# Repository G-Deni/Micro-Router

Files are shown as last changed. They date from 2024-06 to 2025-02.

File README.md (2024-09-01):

# Micro-Router
This project sets out to solve a simple but niche problem, when using any form of hot-spot in a large area coverage can suffer. Using a mesh-network of Micro-Routers coverage area can be extended for a short time without running any cables. This is achieved by a custom OpenWRT configuration and a onboard battery that should yield ~16hrs of run time.

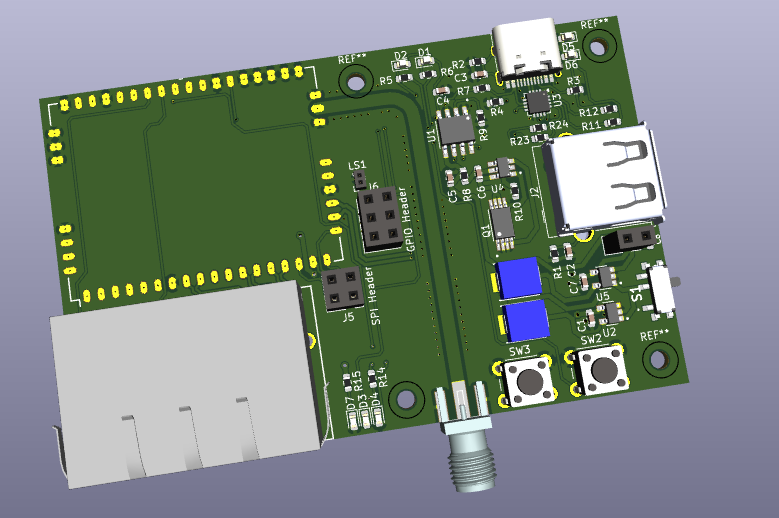
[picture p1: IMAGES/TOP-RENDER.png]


## Features 

### SOM
Each Micro-Router uses a [Carambola2](https://www.8devices.com/products/carambola-2) SOM running [OpenWRT](https://openwrt.org/). 

### Ports
<ul>
  <li>USB-A - Media share capacity</li>
  <li>USB-C - Charging and UART</li>
  <li>2x RJ45 - LAN and WAN</li>
</ul>

### Charge Controller
Powered A 3.3v TP4056 charging circuit with a separate 5v boost converter to power the USB-A port. The charge controller was selected for this project to be cheap, this means while the battery is protected there is no communication between the SOM and the charge controller. There is no safe start of shut down if the battery dies the charge controller will disconnect the battery from the loads. It power switch toggles the boost converters on and off, disconnecting the battery from all loads at the boost converter. The 5v and the 3.3v boost converters are both 500mah and toggled on and off by the same slide switch.

### USB Serial
It has serial output over USB-C to help prevent bricking during development. All of the reset and clock pins are connected to make it as robust as possible, however if there is a problem with the serial connection both the Carambola2 and the serial to USB IC have reset push-buttons. 

### GPIO/SPI Headers
Exposed on the board are two 2.25mm pitch headers one is for SPI screen output (four pin) and one for general GPIO (6 pin).  

### External Antenna
A board mounted SMA connector is impedance matched for 2.4ghz WiFi is exposed for a external antenna to be connected to. There is no internal antenna as the performance is usually very poor.

### Speaker
Two pins are exposed for the speaker one is ground the other is a GPIO. One of the GPIO pins has to be reserved to be used as a speaker. If the extra GPIO pin is needed do not populate the speaker.

## Docking Case
The PCB layout may look rather unconventional but it is intentional. The routers are optimized to be used in a dock configuration.

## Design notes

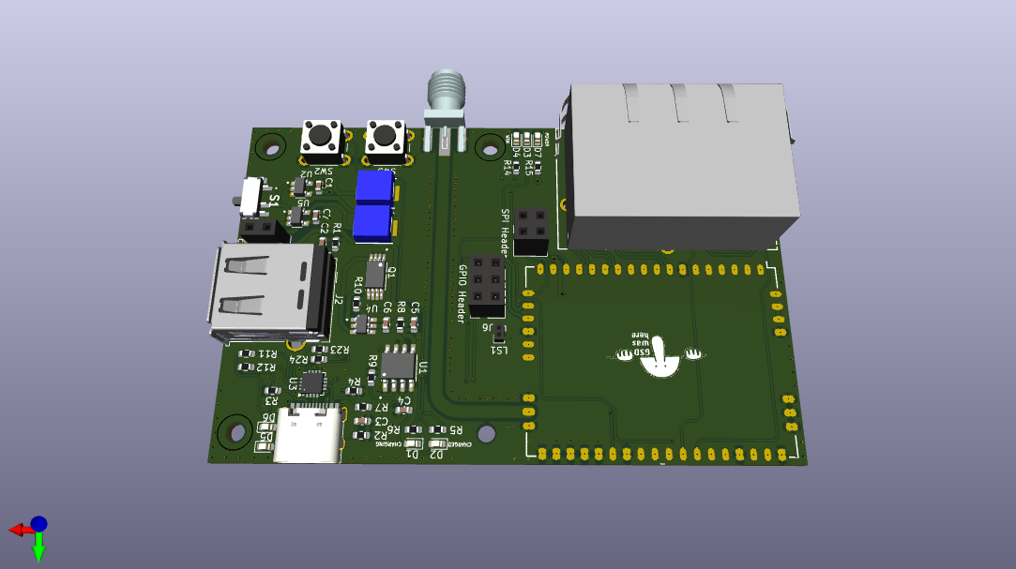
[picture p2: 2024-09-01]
MICRO-ROUTER-PCB/MICRO-ROUTER/MICRO-ROUTER RENDER.png

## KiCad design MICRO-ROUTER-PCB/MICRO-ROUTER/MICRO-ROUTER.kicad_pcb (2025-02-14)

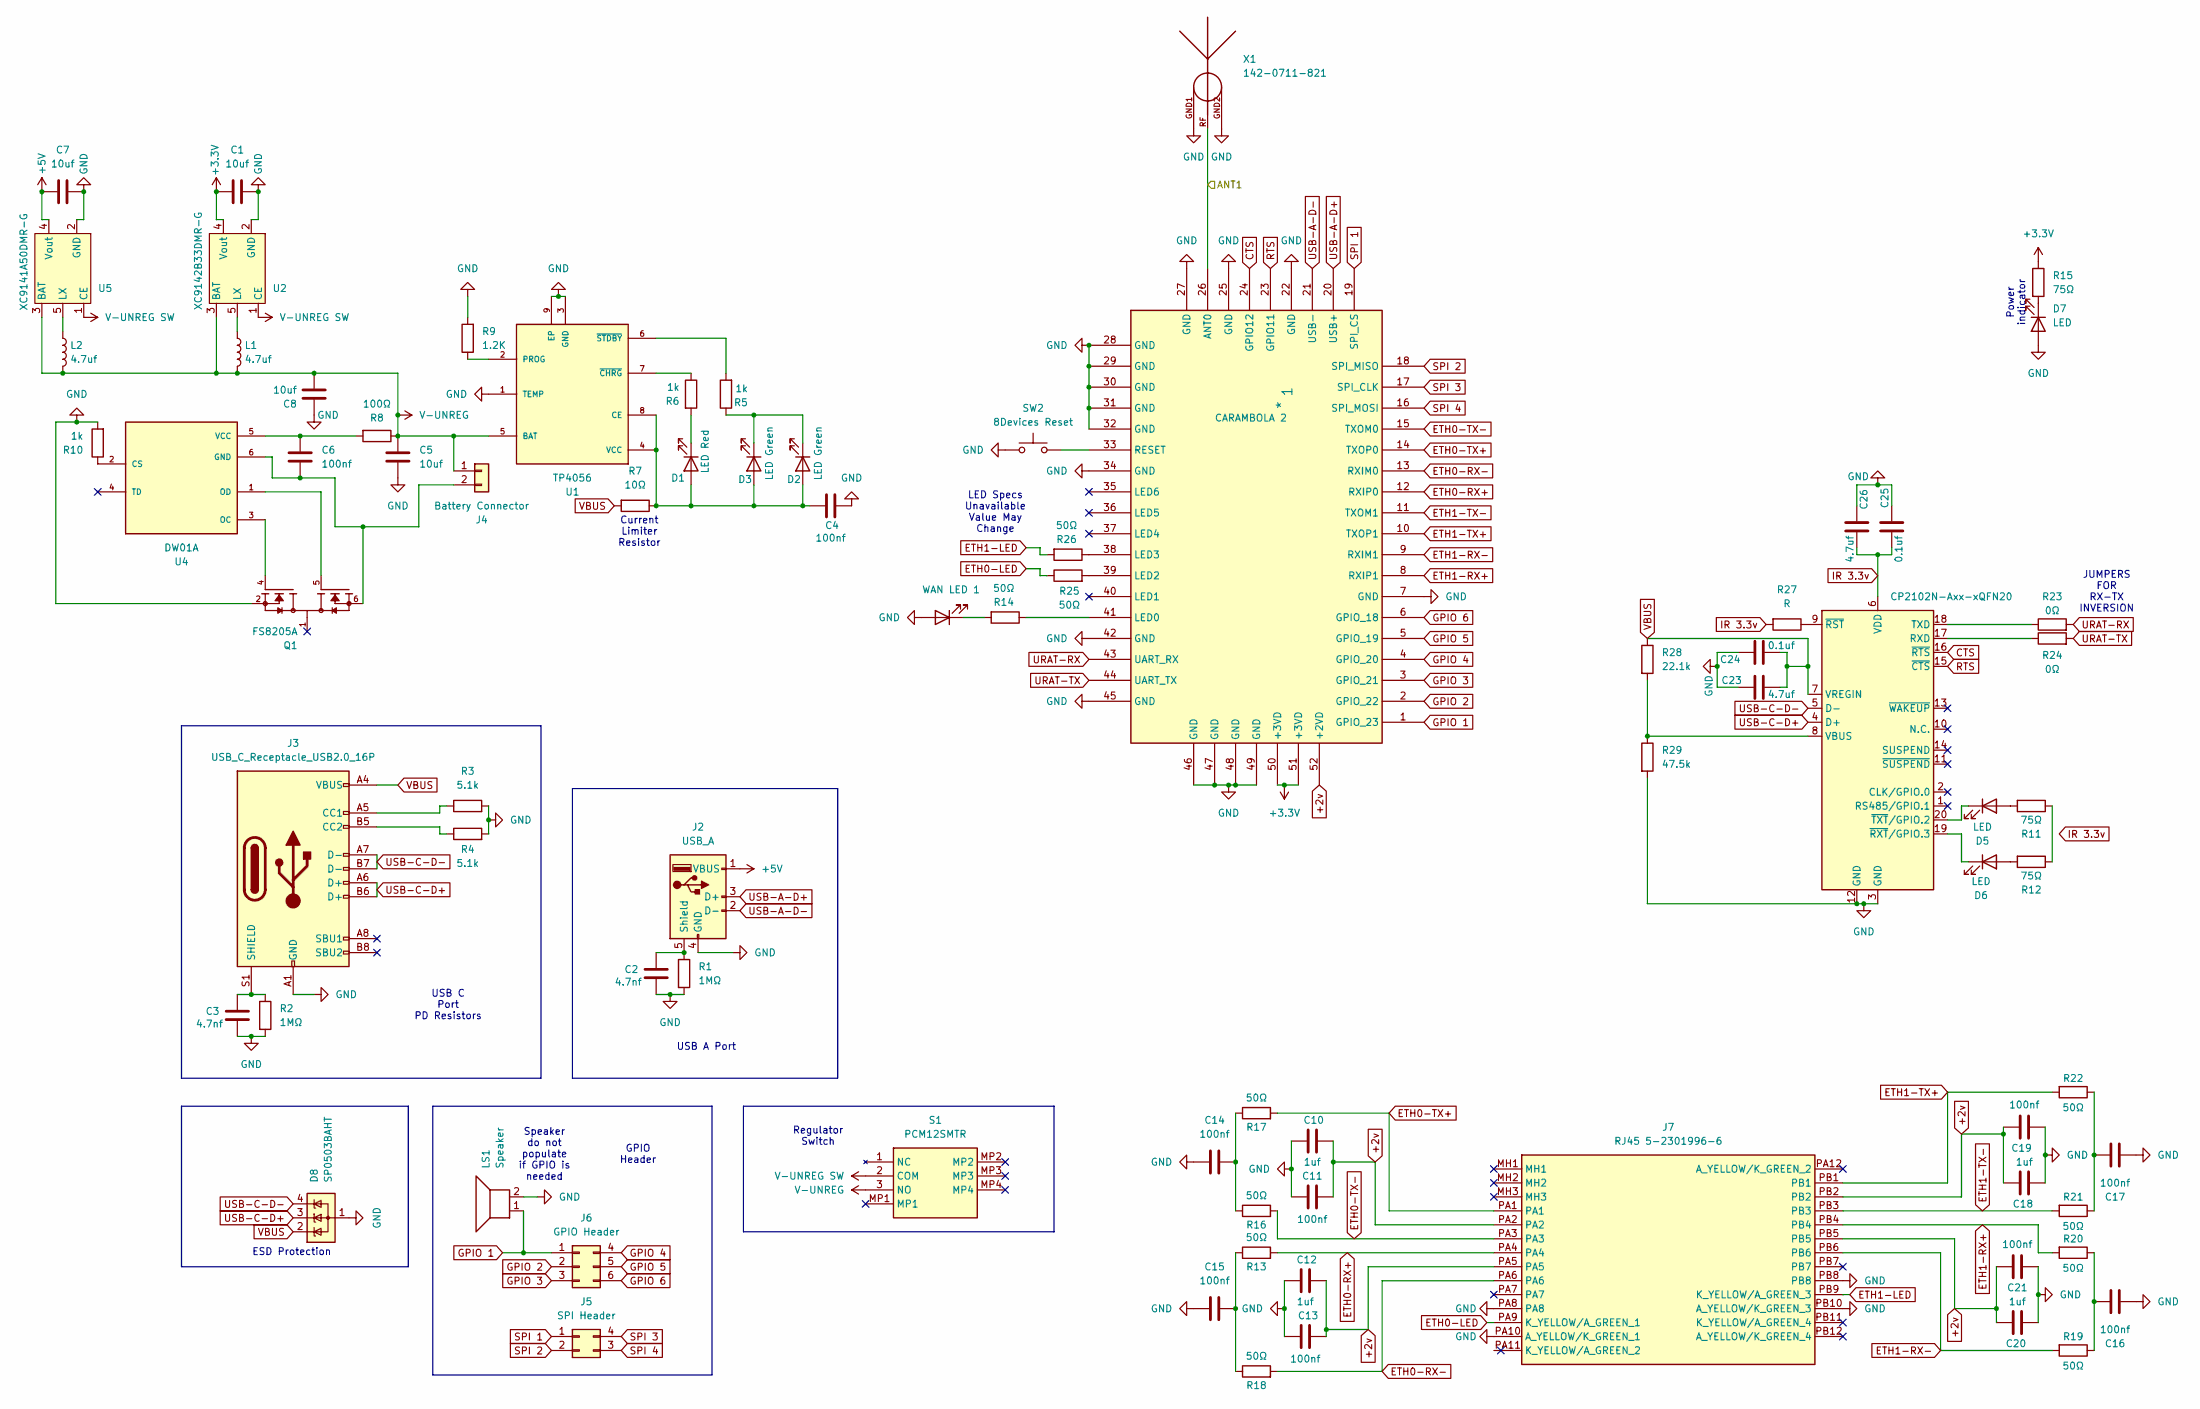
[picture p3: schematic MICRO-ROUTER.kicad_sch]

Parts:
1: *; 8Devices-Carambola2
C1, C5, C7, C8: 10uf; C_0603_1608Metric
C2, C3: 4.7nf; C_0603_1608Metric
C4, C6, C11, C13, C14, C15, C16, C17, C19, C21: 100nf; C_0603_1608Metric
C10, C12, C18, C20: 1uf; C_0603_1608Metric
C23, C26: 4.7uf
C24, C25: 0.1uf
D1: LED Red; LED_0603_1608Metric
D2, D3: LED Green; LED_0603_1608Metric
D4: WAN LED 1; LED_0603_1608Metric
D5, D6, D7: LED; LED_0603_1608Metric
D8: SP0503BAHT; SOT-143
J2: USB_A; USB_A_Molex_67643_Horizontal
J3: USB_C_Receptacle_USB2.0_16P; TYPE-C-31-M-12
J4: Battery Connector; PinSocket_1x02_P2.54mm_Vertical
J5: SPI Header; PinSocket_2x02_P2.54mm_Vertical
J6: GPIO Header; PinSocket_2x03_P2.54mm_Vertical
J7: RJ45 5-2301996-6; RJ45 523019966; Manufacturer_Part_Number 5-2301996-6; Mouser Part Number 571-5-2301996-6
L1, L2: 4.7uf; INDPM5752X300N
LS1: Speaker; PinSocket_1x02_P1.00mm_Vertical
Q1: FS8205A; PARTREV 1.7
R1, R2: 1MΩ; R_0603_1608Metric
R3, R4: 5.1k; R_0603_1608Metric
R5, R6, R10: 1k; R_0603_1608Metric
R7: 10Ω; R_0603_1608Metric
R8: 100Ω; R_0603_1608Metric
R9: 1.2K; R_0603_1608Metric
R11, R12, R15: 75Ω; R_0603_1608Metric
R13, R14, R16, R17, R18, R19, R20, R21, R22, R25, R26: 50Ω; R_0603_1608Metric
R23, R24: 0Ω; R_0603_1608Metric
R27: R
R28: 22.1k
R29: 47.5k
S1: PCM12SMTR; Manufacturer_Part_Number PCM12SMTR; Mouser Part Number 611-PCM12SMTR
SW2: 8Devices Reset; SW_PUSH_6mm
U1: TP4056
U2: XC9142B33DMR-G; XC8107AC20MR-G
U3: CP2102N-Axx-xQFN20; SiliconLabs_QFN-20-1EP_3x3mm_P0.5mm_EP1.8x1.8mm
U4: DW01A; PARTREV 1.8
U5: XC9141A50DMR-G; XC8107AC20MR-G
X1: 142-0711-821; SMA 142-0711-821

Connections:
+2v: 1.52 (+2VD), C10.2, C11.2, C12.2, C13.2, C18.2, C19.2, C20.2, C21.2, J7.PA2, J7.PA5, J7.PB2, J7.PB5
+3.3V: 1.50 (+3VD), 1.51 (+3VD), C1.1, R15.1, U2.4 (Vout)
+5V: C7.1, J2.1 (VBUS), U5.4 (Vout)
/ANT1: 1.26 (ANT0), X1.RF
CTS: 1.24 (GPIO12), U3.16 (~RTS)
ETH0-LED: J7.PA9 (K_YELLOW/A_GREEN_1), R25.1
ETH0-RX+: 1.12 (RXIP0), J7.PA4, R13.2
ETH0-RX-: 1.13 (RXIM0), J7.PA6, R18.2
ETH0-TX+: 1.14 (TXOP0), J7.PA1, R17.2
ETH0-TX-: 1.15 (TXOM0), J7.PA3, R16.2
ETH1-LED: J7.PB9 (K_YELLOW/A_GREEN_3), R26.2
ETH1-RX+: 1.8 (RXIP1), J7.PB4, R20.2
ETH1-RX-: 1.9 (RXIM1), J7.PB6, R19.2
ETH1-TX+: 1.10 (TXOP1), J7.PB1, R22.2
ETH1-TX-: 1.11 (TXOM1), J7.PB3, R21.2
GND: 1.7 (GND), 1.22 (GND), 1.25 (GND), 1.27 (GND), 1.28 (GND), 1.29 (GND), 1.30 (GND), 1.31 (GND), 1.32 (GND), 1.34 (GND), 1.42 (GND), 1.45 (GND), 1.46 (GND), 1.47 (GND), 1.48 (GND), 1.49 (GND), C1.2, C2.2, C3.2, C4.1, C5.1, C7.2, C8.2, C10.1, C11.1, C12.1, C13.1, C14.1, C15.1, C16.1, C17.1, C18.1, C19.1, C20.1, C21.1, C23.2, C24.2, C25.2, C26.2, D4.2 (A), D7.2 (A), D8.1 (A), J2.4 (GND), J3.A1 (GND), J3.A12 (GND), J3.B1 (GND), J3.B12 (GND), J7.PA8, J7.PA10 (A_YELLOW/K_GREEN_1), J7.PB8, J7.PB10 (A_YELLOW/K_GREEN_3), LS1.2, Q1.2, Q1.3, R1.2, R2.2, R3.2, R4.2, R9.2, R10.2, R29.2, SW2.1, U1.1 (TEMP), U1.3 (GND), U1.9 (EP), U2.2 (GND), U3.3 (GND), U3.12 (GND), U3.21 (GND), U5.2 (GND), X1.GND1, X1.GND2
GPIO 1: 1.1 (GPIO_23), J6.1, LS1.1
GPIO 2: 1.2 (GPIO_22), J6.2
GPIO 3: 1.3 (GPIO_21), J6.3
GPIO 4: 1.4 (GPIO_20), J6.4
GPIO 5: 1.5 (GPIO_19), J6.5
GPIO 6: 1.6 (GPIO_18), J6.6
unnamed: 1.41 (LED0), R14.1
unnamed: 1.39 (LED2), R25.2
unnamed: 1.38 (LED3), R26.1
unnamed: 1.33 (RESET), SW2.2
unnamed: C14.2, R16.1, R17.1
unnamed: C15.2, R13.1, R18.1
unnamed: C16.2, R19.1, R20.1
unnamed: C17.2, R21.1, R22.1
unnamed: C4.2, D1.2 (A), D2.2 (A), D3.2 (A), R7.1, U1.4 (VCC), U1.8 (CE)
unnamed: D1.1 (K), R6.2
unnamed: D2.1 (K), D3.1 (K), R5.1
unnamed: D4.1 (K), R14.2
unnamed: D5.2 (A), R11.2
unnamed: D5.1 (K), U3.20 (~TXT/GPIO.2)
unnamed: D6.2 (A), R12.2
unnamed: D6.1 (K), U3.19 (~RXT/GPIO.3)
unnamed: D7.1 (K), R15.2
unnamed: C2.1, J2.5 (Shield), R1.1
unnamed: J3.A5 (CC1), R3.1
unnamed: J3.B5 (CC2), R4.1
unnamed: C3.1, J3.S1 (SHIELD), R2.1
unnamed: C6.1, J4.2, Q1.6, Q1.7, U4.6 (GND)
unnamed: R9.1, U1.2 (PROG)
unnamed: R6.1, U1.7 (~CHRG)
unnamed: R5.2, U1.6 (~STDBY)
unnamed: L1.1, U2.5 (LX)
unnamed: R24.1, U3.17 (RXD)
unnamed: R23.1, U3.18 (TXD)
unnamed: R28.2, R29.1, U3.8 (VBUS)
unnamed: R27.1, U3.9 (~RST)
unnamed: R10.1, U4.2 (CS)
unnamed: Q1.4, U4.3 (OC)
unnamed: Q1.5, U4.1 (OD)
unnamed: C6.2, R8.2, U4.5 (VCC)
unnamed: L2.1, U5.5 (LX)
RTS: 1.23 (GPIO11), U3.15 (~CTS)
SPI 1: 1.19 (SPI_CS), J5.1
SPI 2: 1.18 (SPI_MISO), J5.2
SPI 3: 1.17 (SPI_CLK), J5.4
SPI 4: 1.16 (SPI_MOSI), J5.3
URAT-RX: 1.43 (UART_RX), R23.2
URAT-TX: 1.44 (UART_TX), R24.2
USB-A-D+: 1.20 (USB+), J2.3 (D+)
USB-A-D-: 1.21 (USB-), J2.2 (D-)
USB-C-D+: D8.3 (K), J3.A6 (D+), J3.B6 (D+), U3.4 (D+)
USB-C-D-: D8.4 (K), J3.A7 (D-), J3.B7 (D-), U3.5 (D-)
V-UNREG: C5.2, C8.1, J4.1, L1.2, L2.2, R8.1, S1.3 (NO), U1.5 (BAT), U2.3 (BAT), U5.3 (BAT)
V-UNREG SW: S1.2 (COM), U2.1 (CE), U5.1 (CE)
VBUS: C23.1, C24.1, D8.2 (K), J3.A4 (VBUS), J3.A9 (VBUS), J3.B4 (VBUS), J3.B9 (VBUS), R7.2, R28.1, U3.7 (VREGIN)

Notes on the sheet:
JUMPERS FOR RX-TX INVERSION
ESD Protection
Current Limiter Resistor
USB A Port
Power indicator
Speaker do not populate if GPIO is needed
Regulator Switch
USB C Port PD Resistors
GPIO Header
LED Specs Unavailable Value May Change

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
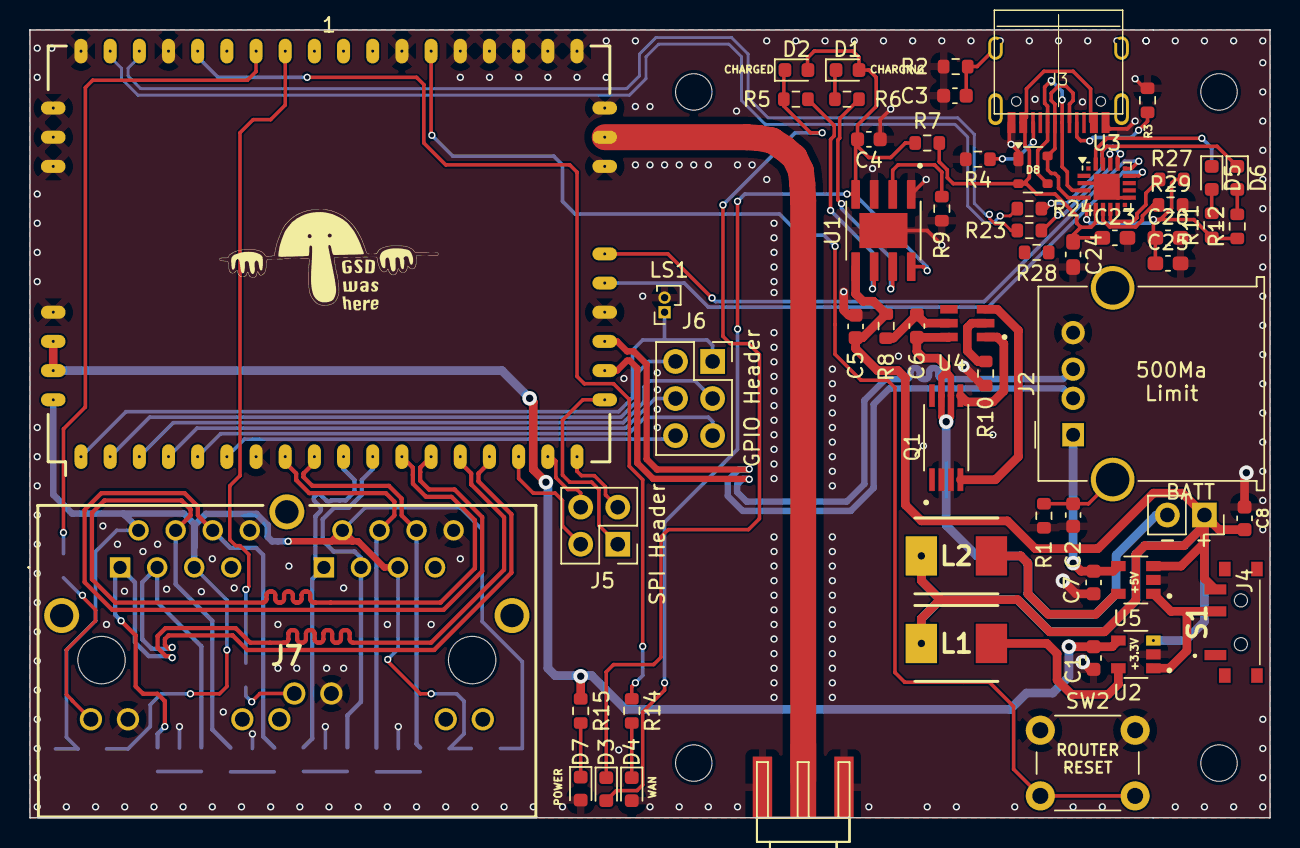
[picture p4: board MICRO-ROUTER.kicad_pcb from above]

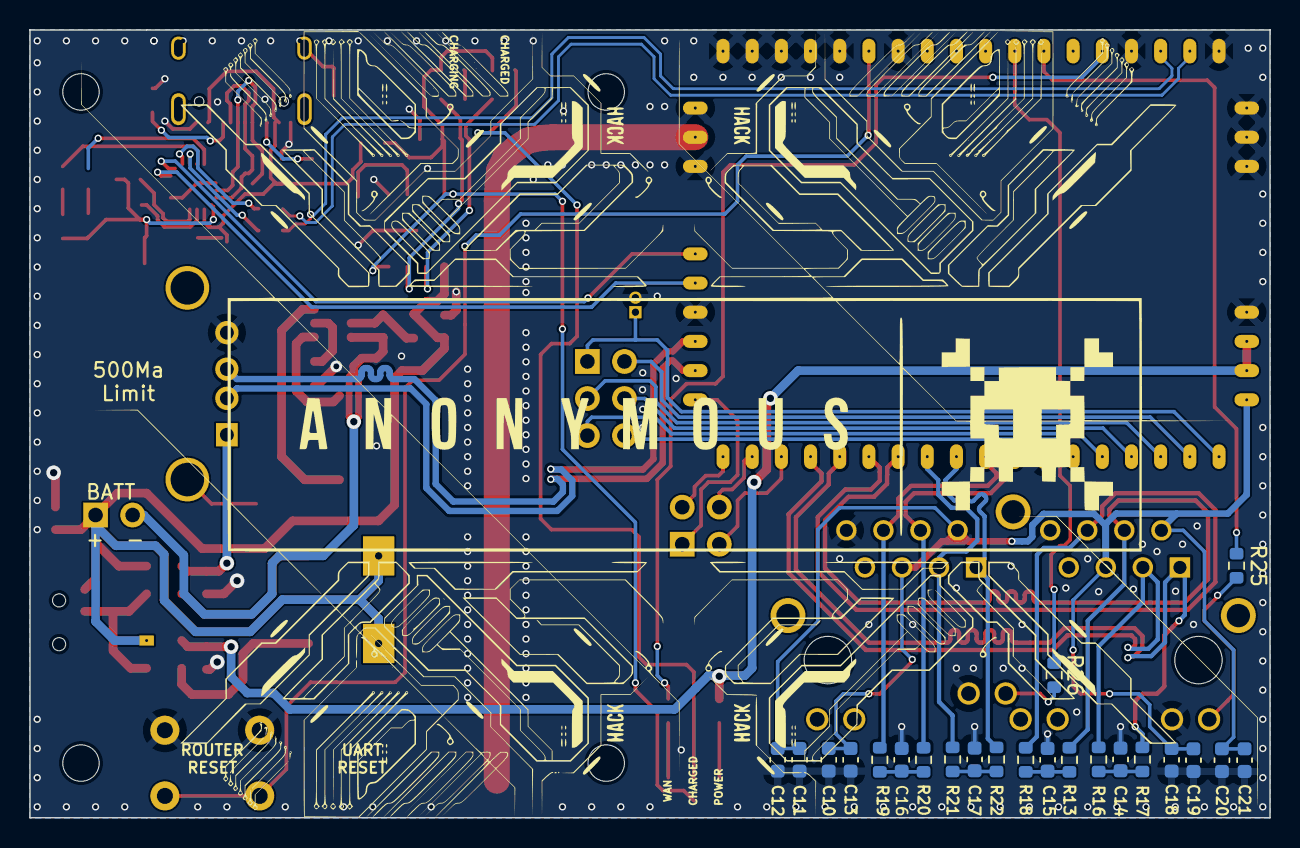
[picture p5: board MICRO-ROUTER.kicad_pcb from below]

Board: 2 copper layers, 85.0 x 54.0 mm, 80 parts (22 on the bottom side), 72 nets.

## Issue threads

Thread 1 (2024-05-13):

Buzzer footprint

G-Deni, 2024-05-13:
https://www.digikey.com/en/products/detail/visaton-gmbh-co-kg/PB-9-9-3-V/10650372
Need to make footprint for buzzer

Closed 2024-05-28.

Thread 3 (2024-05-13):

TTL to USB LED

The-Prof12, 2024-05-13:
LEDs need to be wired up

The-Prof12, 2024-05-14:
Fixed

Closed 2024-05-14.

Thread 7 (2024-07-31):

RTS CTS pins are not inverted

G-Deni, 2024-07-31:
May cause TTL problems

G-Deni, 2024-09-01:
Fixed in schematics

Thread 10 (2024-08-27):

Regulator Not Disabled

G-Deni, 2024-08-27:
Caps need to be added to fully disable the 3.3v regulator

G-Deni, 2024-09-01:
-Fixed schematics
-Needs to be done

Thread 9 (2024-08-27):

Reset USB TTL

G-Deni, 2024-08-27:
Button is wired to the VREG

G-Deni, 2024-09-01:
Removed in schematics

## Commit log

2024-04-29 Intal commit after https vs ssh fix
    [MICRO-ROUTER.kicad_pcb, MICRO-ROUTER.kicad_sch]
2024-05-01 Started work on schem, finished voltage reg and charge daughter board
    [MICRO-ROUTER.kicad_sch]
2024-05-02 Added USB 3.0 Started adding onboard URAT to TTL
    [MICRO-ROUTER.kicad_sch]
2024-05-05 routine back up
    [MICRO-ROUTER.kicad_sch]
2024-05-08 Swapped SOM due to lower wattage Worked on scematic -UART IC -USB C PORT -USB 2.0 PORT
    [MICRO-ROUTER.kicad_sch]
2024-05-12 finished charger
    [MICRO-ROUTER.kicad_sch]
2024-05-13 Added V regulator Added GPIO header Added SPI header Added WAN LED Fixed incorect component values Added tags for LAN
2024-05-14 Fixed rx tx LEDs Did footprint asociation
    [MICRO-ROUTER.kicad_sch]
2024-05-21 wirred rj45 port and power
    [MICRO-ROUTER.kicad_sch]
2024-05-28 -Finish rj45 leds -Added notes to schem -Fixed missing footprints -Preped for layout -Wired Eth1
    [MICRO-ROUTER.kicad_pcb, MICRO-ROUTER.kicad_sch]
2024-05-28 fixed footprint error
    [MICRO-ROUTER.kicad_sch]
2024-05-29 -began layout -fixed several errors in formating -fixed assocition errors
    [MICRO-ROUTER.kicad_pcb, MICRO-ROUTER.kicad_sch]
2024-05-30 -worked on more layout
    [MICRO-ROUTER.kicad_pcb]
2024-05-30 - Finished Usb C layout
    [MICRO-ROUTER.kicad_pcb]
2024-06-04 routed rj45 lines
    [MICRO-ROUTER.kicad_pcb]
2024-06-04 -wired sma connector
    [MICRO-ROUTER.kicad_pcb, MICRO-ROUTER.kicad_sch]
2024-06-07 -added extra charge LED -wired TP4056
    [MICRO-ROUTER.kicad_pcb, MICRO-ROUTER.kicad_sch]
2024-06-09 -Wired up Mofset
    [MICRO-ROUTER.kicad_pcb, MICRO-ROUTER.kicad_sch]
2024-06-20 fixed reg
    [MICRO-ROUTER.kicad_pcb, MICRO-ROUTER.kicad_sch]
2024-06-21 -wired 5v and 3.3v reg -cleaned up remaining footprints
    [MICRO-ROUTER.kicad_pcb]
2024-06-23 wired power rails
    [MICRO-ROUTER.kicad_pcb]
2024-06-24 wired cap array for rj45
    [MICRO-ROUTER.kicad_pcb]
2024-06-25 finished layout
    [MICRO-ROUTER.kicad_pcb]
2024-06-25 -Finished layout -Added GND vias -Added rendering photo -3d model association
    [MICRO-ROUTER.kicad_pcb]
2024-07-08 - fixed skew - fixed GND islands - moved some dif pairs to reduce loss - added silk
    [MICRO-ROUTER.kicad_pcb]
2024-07-08 -added decrotive silk -ran drc -fixed small layout errors
    [MICRO-ROUTER.kicad_pcb]
2024-07-13 -added output files for rev00
    [MICRO-ROUTER.csv, MICRO-ROUTER.kicad_pcb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]
2024-07-24 adeed bom
2024-09-01 -fixed all open issues in the schematic
    [MICRO-ROUTER.kicad_pcb, MICRO-ROUTER.kicad_sch]
2024-09-08 -Unrouted PCB Errors
    [MICRO-ROUTER.kicad_pcb]
2024-12-22 -Fixed the ttl adapter (this time should be right)
    [MICRO-ROUTER.kicad_pcb, MICRO-ROUTER.kicad_sch]
2025-02-14 backup before wipe
    [MICRO-ROUTER.kicad_pcb]
